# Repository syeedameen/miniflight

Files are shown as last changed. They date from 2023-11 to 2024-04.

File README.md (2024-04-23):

# miniflight
Budget Flight Controller for Drones with ATmega328P Microcontroller

- MPU6050 - Inertial Measurement Unit
- BMP280 - Prassure & temprature sensor
- ATmega328p Microcontroller
- 2-layer PCB design in KiCad EDA (manufactured from JLCPCB)
- 45 x 45 mm PCB size

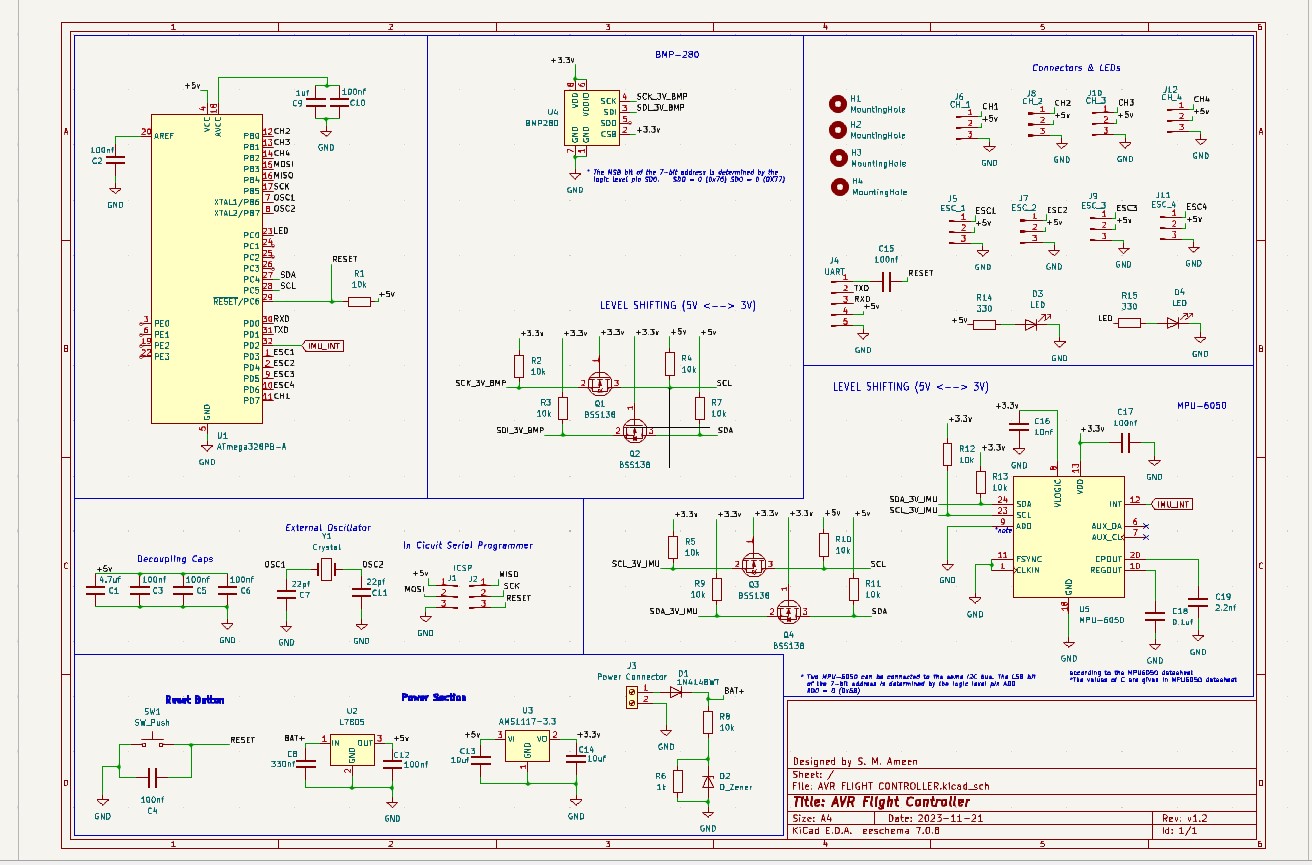
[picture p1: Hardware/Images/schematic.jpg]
Schematic
  
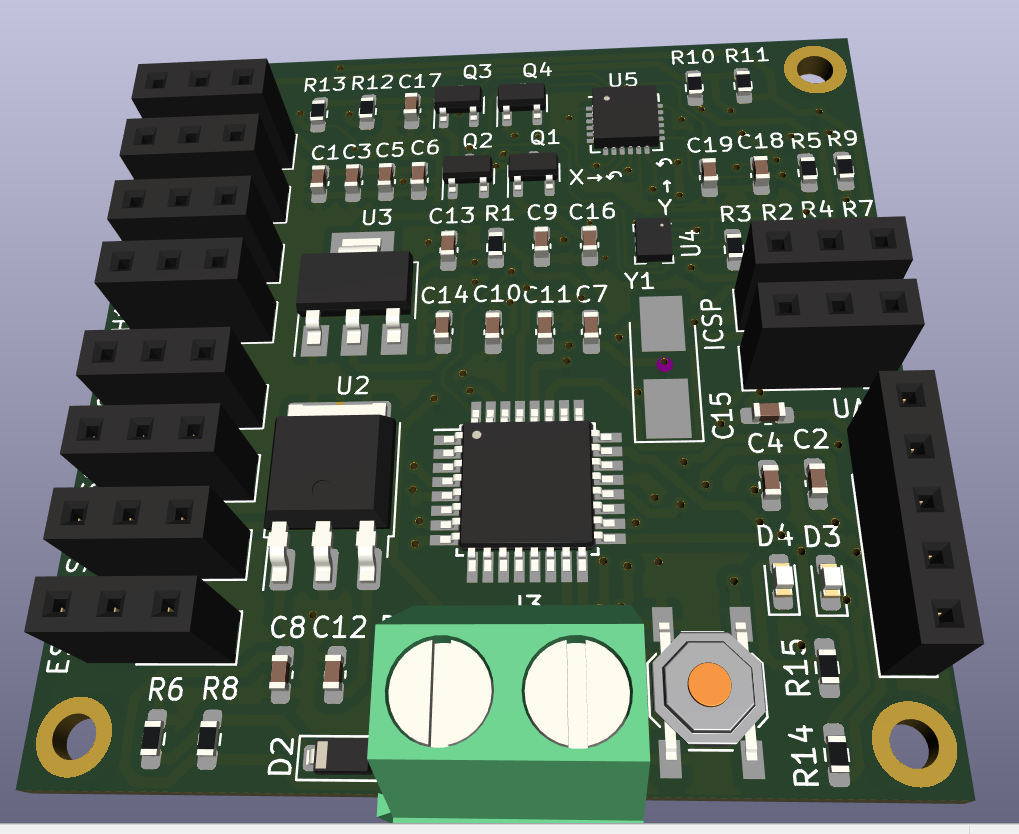
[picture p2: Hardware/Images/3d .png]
3D view
 
 
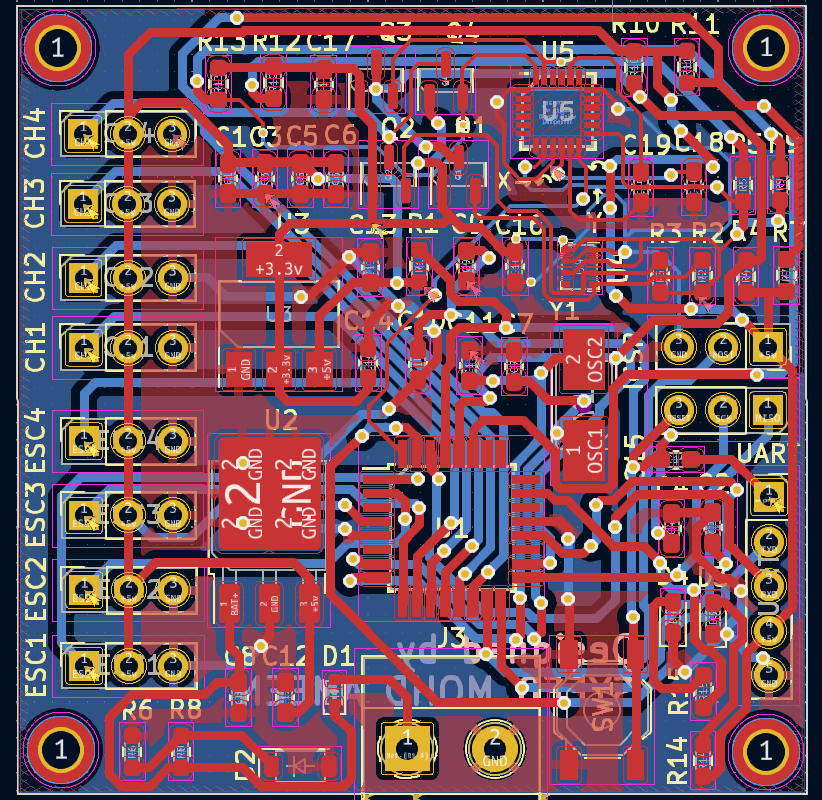
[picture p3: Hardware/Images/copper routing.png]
Copper routing


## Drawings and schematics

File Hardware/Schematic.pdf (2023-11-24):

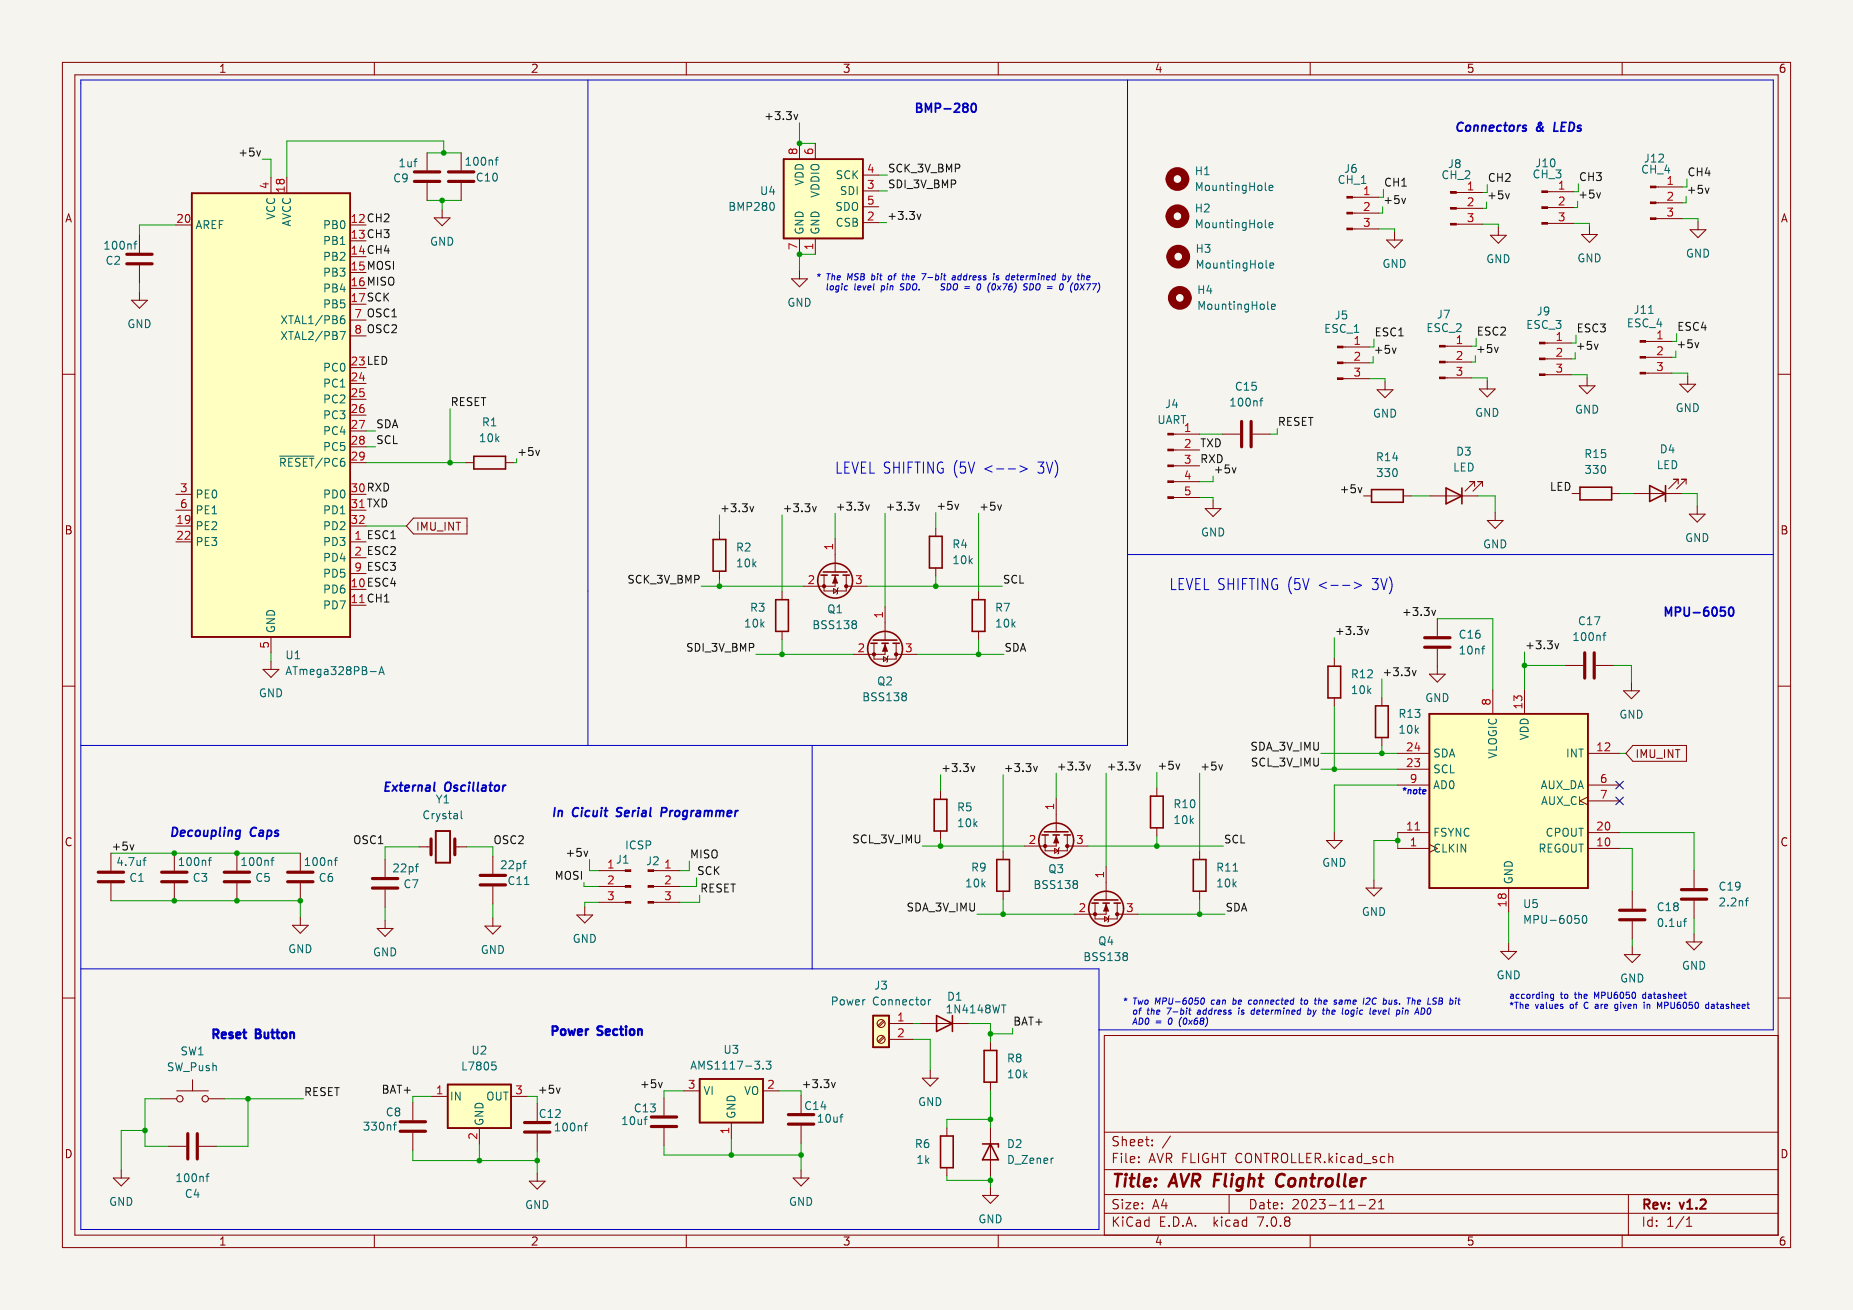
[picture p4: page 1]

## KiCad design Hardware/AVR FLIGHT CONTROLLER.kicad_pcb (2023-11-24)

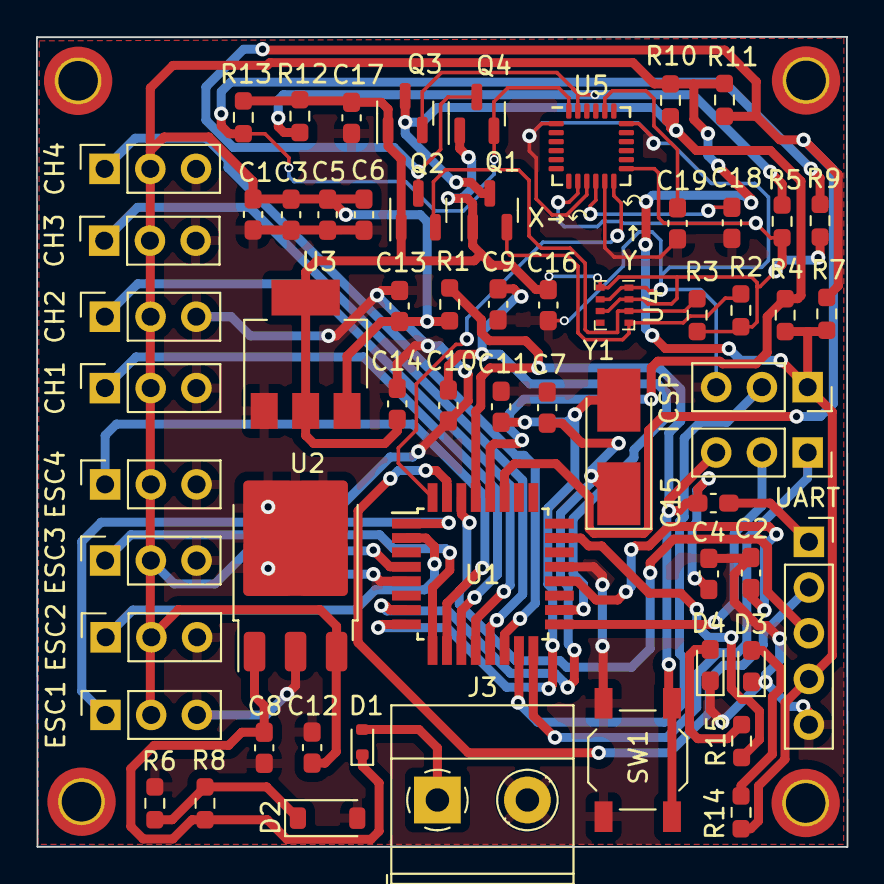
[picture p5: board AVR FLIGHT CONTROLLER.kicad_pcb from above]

Board: 2 copper layers, 45.0 x 45.0 mm, 65 parts (0 on the bottom side), 37 nets.

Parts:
C1: 4.7uf; C_0603_1608Metric_Pad1.08x0.95mm_HandSolder
C2, C3, C4, C5, C6, C10, C12, C15, C17: 100nf; C_0603_1608Metric_Pad1.08x0.95mm_HandSolder
C7, C11: 22pf; C_0603_1608Metric_Pad1.08x0.95mm_HandSolder
C8: 330nf; C_0603_1608Metric_Pad1.08x0.95mm_HandSolder
C9: 1uf; C_0603_1608Metric_Pad1.08x0.95mm_HandSolder
C13, C14: 10uf; C_0603_1608Metric_Pad1.08x0.95mm_HandSolder
C16: 10nf; C_0603_1608Metric_Pad1.08x0.95mm_HandSolder
C18: 0.1uf; C_0603_1608Metric_Pad1.08x0.95mm_HandSolder
C19: 2.2nf; C_0603_1608Metric_Pad1.08x0.95mm_HandSolder
CH1: CH_1; PinSocket_1x03_P2.54mm_Vertical
CH2: CH_2; PinSocket_1x03_P2.54mm_Vertical
CH3: CH_3; PinSocket_1x03_P2.54mm_Vertical
CH4: CH_4; PinSocket_1x03_P2.54mm_Vertical
D1: 1N4148WT; D_SOD-523
D2: D_Zener; D_SOD-123
D3, D4: LED; LED_0603_1608Metric_Pad1.05x0.95mm_HandSolder
ESC1: ESC_1; PinSocket_1x03_P2.54mm_Vertical
ESC2: ESC_2; PinSocket_1x03_P2.54mm_Vertical
ESC3: ESC_3; PinSocket_1x03_P2.54mm_Vertical
ESC4: ESC_4; PinSocket_1x03_P2.54mm_Vertical
H1, H2, H3, H4: MountingHole; MountingHole_2.2mm_M2_DIN965_Pad_TopBottom
J1: PinSocket_1x03_P2.54mm_Vertical
J2: ICSP; PinSocket_1x03_P2.54mm_Vertical
J3: Power Connector; TerminalBlock_Phoenix_MKDS-1,5-2_1x02_P5.00mm_Horizontal
Q1, Q2, Q3, Q4: BSS138; SOT-23
R1, R2, R3, R4, R5, R7, R8, R9, R10, R11, R12, R13: 10k; R_0603_1608Metric_Pad0.98x0.95mm_HandSolder
R6: 1k; R_0603_1608Metric_Pad0.98x0.95mm_HandSolder
R14, R15: 330; R_0603_1608Metric_Pad0.98x0.95mm_HandSolder
SW1: SW_Push; SW_SPST_TL3342
U1: ATmega328PB-A; TQFP-32_7x7mm_P0.8mm
U2: L7805; TO-252-3_TabPin2
U3: AMS1117-3.3; SOT-223-3_TabPin2
U4: BMP280; Bosch_LGA-8_2x2.5mm_P0.65mm_ClockwisePinNumbering
U5: MPU-6050; InvenSense_QFN-24_4x4mm_P0.5mm
UART: UART; PinSocket_1x05_P2.54mm_Vertical
Y1: Crystal; Crystal_SMD_5032-2Pin_5.0x3.2mm_HandSoldering

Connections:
/+3.3v: C14.1, C16.1, C17.1, Q1.1 (G), Q2.1 (G), Q3.1 (G), Q4.1 (G), R2.1, R3.1, R5.1, R9.1, R12.1, R13.1, U3.2 (VO), U4.2 (CSB), U4.6 (VDDIO), U4.8 (VDD), U5.8 (VLOGIC), U5.13 (VDD)
/+5v: C1.2, C3.2, C5.2, C6.2, C12.1, C13.1, CH1.2, CH2.2, CH3.2, CH4.2, ESC1.2, ESC2.2, ESC3.2, ESC4.2, J1.1, R1.2, R4.1, R7.1, R10.1, R11.1, R14.1, U1.4 (VCC), U2.3 (OUT), U3.3 (VI), UART.4
/BAT+: C8.1, D1.1 (K), R8.1, U2.1 (IN)
/CH1: CH1.1, U1.11 (PD7)
/CH2: CH2.1, U1.12 (PB0)
/CH3: CH3.1, U1.13 (PB1)
/CH4: CH4.1, U1.14 (PB2)
/ESC1: ESC1.1, U1.1 (PD3)
/ESC2: ESC2.1, U1.2 (PD4)
/ESC3: ESC3.1, U1.9 (PD5)
/ESC4: ESC4.1, U1.10 (PD6)
/LED: R15.1, U1.23 (PC0)
/MISO: J2.1, U1.16 (PB4)
/MOSI: J1.2, U1.15 (PB3)
/OSC1: C7.2, U1.7 (XTAL1/PB6), Y1.1
/OSC2: C11.2, U1.8 (XTAL2/PB7), Y1.2
/RESET: C4.2, C15.2, J2.3, R1.1, SW1.2, U1.29 (~RESET/PC6)
/RXD: U1.30 (PD0), UART.3
/SCK: J2.2, U1.17 (PB5)
/SCK_3V_BMP: Q1.2 (S), R2.2, U4.4 (SCK)
/SCL: Q1.3 (D), Q3.3 (D), R4.2, R10.2, U1.28 (PC5)
/SCL_3V_IMU: Q3.2 (S), R5.2, R12.2, U5.23 (SCL)
/SDA: Q2.3 (D), Q4.3 (D), R7.2, R11.2, U1.27 (PC4)
/SDA_3V_IMU: Q4.2 (S), R9.2, R13.2, U5.24 (SDA)
/SDI_3V_BMP: Q2.2 (S), R3.2, U4.3 (SDI)
/TXD: U1.31 (PD1), UART.2
GND: C1.1, C2.1, C3.1, C4.1, C5.1, C6.1, C7.1, C8.2, C9.1, C10.1, C11.1, C12.2, C13.2, C14.2, C16.2, C17.2, C18.2, C19.2, CH1.3, CH2.3, CH3.3, CH4.3, D2.2 (A), D3.1 (K), D4.1 (K), ESC1.3, ESC2.3, ESC3.3, ESC4.3, J1.3, J3.2, R6.2, SW1.1, U1.5 (GND), U1.21 (GND), U2.2 (GND), U3.1 (GND), U4.1 (GND), U4.7 (GND), U5.1 (CLKIN), U5.9 (AD0), U5.11 (FSYNC), U5.18 (GND), UART.5
IMU_INT: U1.32 (PD2), U5.12 (INT)
unnamed: D1.2 (A), J3.1
unnamed: D2.1 (K), R6.1, R8.2
unnamed: D3.2 (A), R14.2
unnamed: D4.2 (A), R15.2
unnamed: C15.1, UART.1
unnamed: C2.2, U1.20 (AREF)
unnamed: C9.2, C10.2, U1.18 (AVCC)
unnamed: C19.1, U5.20 (CPOUT)
unnamed: C18.1, U5.10 (REGOUT)
